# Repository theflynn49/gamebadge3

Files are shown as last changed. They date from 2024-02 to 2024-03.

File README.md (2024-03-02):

<b>New 2024 march 2</b> : Good news : all screens work, including the 7-pins ones ! 
Read the details in ST7789_280x240/TFT_adapt/README.md

This a a fork of BenHeck's GameBadge3 repo

I have a branch here "ST7789_280x240" where I made some changes
to support wider screens

There is also a TZT_adapt directory with gerber files for an adapter for cheap AliExpress screens (ST7789V screens with a connector layout like (Gnd/Vcc/Scl/Sda/Res/DC/CS/Blk)

To use it, modify code/Arduino libraries/pico_ST7789/pico_ST7789.cpp to set the width of your physical screen, i.e. 320, 280 or 240.
You should set also the appropriate rotation, leaving it to "1" if possible by rotating physically the screen (soldering it
in the left or right slot of the TZT adpter) 

If you do that, NOT-recompiled games may work on your screen without modifications,

exemple :
  #define SCR_WIDTH 320
  #define LCD_ROTATION 1

and then you should recompile.

Centering vertically has not been done yet, and will probably never be.

Don't forget to do all this on the correct branch :

<code>
git clone https://github.com/theflynn49/gamebadge3.git
git checkout ST7789_280x240
</code>

Warning : Games for GB3 must be compiled with 
  - flash size=1MB / Sketch Size=1MB
  - CPU Speed = 125Mhz (important !)
  - USB Stack : Adafruit TinyUSB



Have fun.
jF

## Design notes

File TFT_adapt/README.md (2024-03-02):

This is a kicad project for an adapter board to install a cheap Aliexpress TZT screen on your GameBadge.

Beware : BenHeck is NOT recommanding this, since cheap display modules may not work well.

On another hand, they cost about $3 instead of $17 as of today.

I tried these up to now :
 
 - <url>https://fr.aliexpress.com/item/1005005921876295.html</url> (round corners without pixels, upside-down)
 - <url>https://fr.aliexpress.com/item/1005005933513340.html</url> (tested OK, is upside-down)
 - <url>https://fr.aliexpress.com/item/32858069771.html</url> (7-wires, tested OK, is upside down)

For the 7-bit screen, you need to change gameBadgePico.cpp, and make the following change :
<code>
const struct st7789_config lcd_config = {
    .spi      = PICO_DEFAULT_SPI_INSTANCE,
    .gpio_din = PICO_DEFAULT_SPI_TX_PIN,
    .gpio_clk = PICO_DEFAULT_SPI_SCK_PIN,
    .gpio_cs  = PICO_DEFAULT_SPI_CSN_PIN,
    .gpio_dc  = 20,
    .gpio_rst = 21,
    .gpio_bl  = 22
};
</code>

has to be replaced by :
<code>
const struct st7789_config lcd_config = {
    .spi      = PICO_DEFAULT_SPI_INSTANCE,
    .gpio_din = PICO_DEFAULT_SPI_TX_PIN,
    .gpio_clk = PICO_DEFAULT_SPI_SCK_PIN,
    .gpio_cs  = -1, // <- to indicate only 7 pins, no CS
    .gpio_dc  = 20,
    .gpio_rst = 21,
    .gpio_bl  =  PICO_DEFAULT_SPI_CSN_PIN // <- if you use my TFT_adapt board this will be misrouted, so use CS instead of BLK
};
</code>
and you'll leave the pin "Blk" not connected on all connectors.
<br/>
Important note : make sure you use my version of gameBadgePico.cpp (as of 2024/02/24), which contains a modification to make the chinese TZT screen stable.
I pushed this mod on both my branches of this repo.

I tested the gerber files with PCBway.

This has been tested now, it works fine. 

Have fun.

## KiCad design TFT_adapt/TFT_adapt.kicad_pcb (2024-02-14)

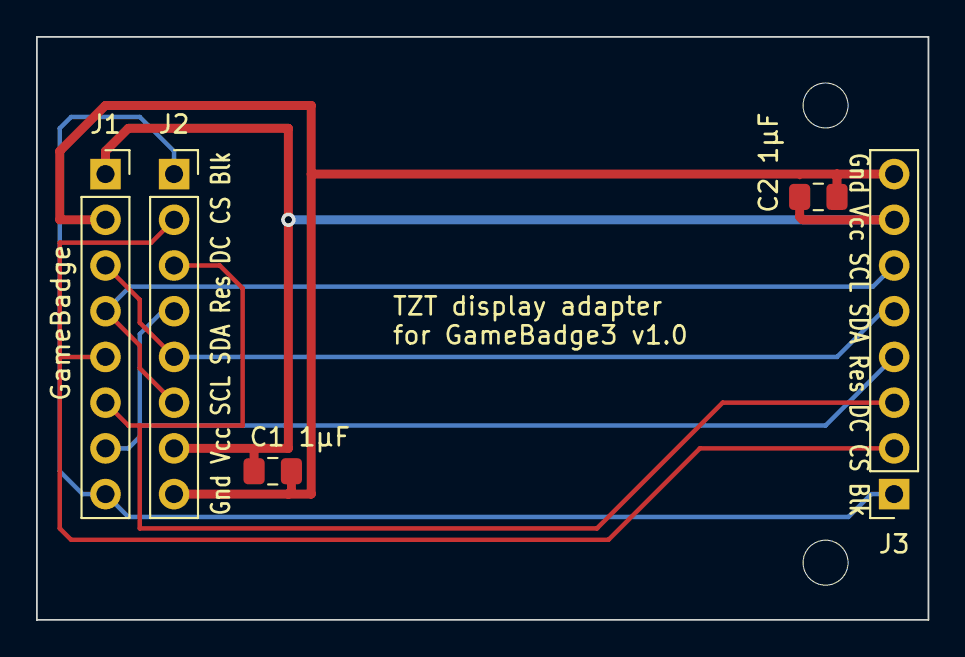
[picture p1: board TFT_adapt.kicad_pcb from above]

Board: 2 copper layers, 49.5 x 32.4 mm, 7 parts (0 on the bottom side), 8 nets.

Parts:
C1 1µF, C2 1µF: 1µF; C_0805_2012Metric_Pad1.18x1.45mm_HandSolder
H1, H2: MountingHole; MountingHole_2.5mm
J1, J2, J3: Conn_01x08; PinSocket_1x08_P2.54mm_Vertical

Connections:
unnamed: C1 1µF.1, C2 1µF.1, J1.1, J2.7, J3.7
unnamed: C1 1µF.2, C2 1µF.2, J1.2, J2.8, J3.8
unnamed: J1.3, J2.5, J3.5
unnamed: J1.4, J2.6, J3.6
unnamed: J1.5, J2.2, J3.2
unnamed: J1.6, J2.3, J3.3
unnamed: J1.7, J2.4, J3.4
unnamed: J1.8, J2.1, J3.1

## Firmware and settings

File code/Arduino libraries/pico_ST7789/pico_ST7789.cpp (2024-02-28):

//ST7789 driver for Pi Pico based Gamebadge3
//Uses this library mostly for setup then dumps data via DMA

#include "Arduino.h"
#include "pico_ST7789.h"

#include <string.h>
#include "hardware/gpio.h"

struct st7789_config st7789_cfg;
uint16_t st7789_width;
uint16_t st7789_height;
bool st7789_data_mode = false;

#define ST77XX_MADCTL_MY 0x80
#define ST77XX_MADCTL_MX 0x40

#define ST77XX_MADCTL_MV 0x20
#define ST77XX_MADCTL_ML 0x10

#define ST77XX_MADCTL_RGB 0x00

#define SCR_WIDTH 320    // Beware some 280x240 screens are in fact 320x240 screens

#define LCD_OFFSET_X ((SCR_WIDTH-240)/2) // set his to (screen width-240)/2, to set black bands left and right
#define SCR_OFFSET_X (320-SCR_WIDTH)     // set this to 320-screen width 
#define LCD_OFFSET_Y 0   // not used yet leave it to 0
#define LCD_ROTATION 1

uint8_t _xstart;
uint8_t _ystart;

void st7789_init(const struct st7789_config* config, uint16_t width, uint16_t height)
{
    memcpy(&st7789_cfg, config, sizeof(st7789_cfg));				//Copy referenced structure to our own copy
    st7789_width = width;
    st7789_height = height;

    spi_init(st7789_cfg.spi, 125 * 1000 * 1000);					//Set SPI to max speed, CPU must be 125Hz
    
    
    if (st7789_cfg.gpio_cs > -1) {
        spi_set_format(st7789_cfg.spi, 8, SPI_CPOL_0, SPI_CPHA_0, SPI_MSB_FIRST);
    } else {
        spi_set_format(st7789_cfg.spi, 8, SPI_CPOL_1, SPI_CPHA_1, SPI_MSB_FIRST);
    }

    gpio_set_function(st7789_cfg.gpio_din, GPIO_FUNC_SPI);
    gpio_set_function(st7789_cfg.gpio_clk, GPIO_FUNC_SPI);

    if (st7789_cfg.gpio_cs > -1) {
        gpio_init(st7789_cfg.gpio_cs);
    }
    gpio_init(st7789_cfg.gpio_dc);
    gpio_init(st7789_cfg.gpio_rst);
    gpio_init(st7789_cfg.gpio_bl);

    if (st7789_cfg.gpio_cs > -1) {
        gpio_set_dir(st7789_cfg.gpio_cs, GPIO_OUT);
    }
    gpio_set_dir(st7789_cfg.gpio_dc, GPIO_OUT);
    gpio_set_dir(st7789_cfg.gpio_rst, GPIO_OUT);
    gpio_set_dir(st7789_cfg.gpio_bl, GPIO_OUT);

	gpio_put(st7789_cfg.gpio_bl, 1);

    if (st7789_cfg.gpio_cs > -1) {
        gpio_put(st7789_cfg.gpio_cs, 1);
    }
    gpio_put(st7789_cfg.gpio_dc, 1);
	gpio_put(st7789_cfg.gpio_rst, 0);
	sleep_ms(150);
    gpio_put(st7789_cfg.gpio_rst, 1);
    sleep_ms(100);
    
    // SWRESET (01h): Software Reset
    st7789_cmd(0x01, NULL, 0);
    sleep_ms(150);

    // SLPOUT (11h): Sleep Out
    st7789_cmd(0x11, NULL, 0);
    sleep_ms(10);

	st7789_setRotation(LCD_ROTATION);

    // COLMOD (3Ah): Interface Pixel Format
    // - RGB interface color format     = 65K of RGB interface
    // - Control interface color format = 16bit/pixel

    //uint8_t cmd = 0x2c;
    //spi_write_blocking(st7789_cfg.spi, &cmd, sizeof(cmd));
    
    uint8_t cmd = 0x55;
    st7789_cmd(0x3a, &cmd, 1);
    sleep_ms(10);

    st7789_caset(0, width - 1);
    st7789_raset(0, height - 1);
	
    // INVON (21h): Display Inversion On
    st7789_cmd(0x21, NULL, 0);
    sleep_ms(10);

    // NORON (13h): Normal Display Mode On
    st7789_cmd(0x13, NULL, 0);
    sleep_ms(10);

    st7789_razmem() ;
    
    // DISPON (29h): Display On
    st7789_cmd(0x29, NULL, 0);
    sleep_ms(10);
	 
}

void st7789_backlight(bool state) {

	if (state == true) {
		gpio_put(st7789_cfg.gpio_bl, 1);
	}
	else {
		gpio_put(st7789_cfg.gpio_bl, 0);
	}
	
}

void st7789_cmd(uint8_t cmd, const uint8_t* data, size_t len)
{
    if (st7789_cfg.gpio_cs > -1) {
        spi_set_format(st7789_cfg.spi, 8, SPI_CPOL_0, SPI_CPHA_0, SPI_MSB_FIRST);
    } else {
        spi_set_format(st7789_cfg.spi, 8, SPI_CPOL_1, SPI_CPHA_1, SPI_MSB_FIRST);
    }
    st7789_data_mode = false;

    sleep_us(1);
    if (st7789_cfg.gpio_cs > -1) {
        gpio_put(st7789_cfg.gpio_cs, 0);
    }
    gpio_put(st7789_cfg.gpio_dc, 0);
    sleep_us(1);
    
    spi_write_blocking(st7789_cfg.spi, &cmd, sizeof(cmd));
    
    if (len) {
        sleep_us(1);
        gpio_put(st7789_cfg.gpio_dc, 1);
        sleep_us(1);
        
        spi_write_blocking(st7789_cfg.spi, data, len);
    }

    sleep_us(1);
    if (st7789_cfg.gpio_cs > -1) {
        gpio_put(st7789_cfg.gpio_cs, 1);
    }
    gpio_put(st7789_cfg.gpio_dc, 1);
    sleep_us(1);
}


void st7789_rascaset(uint8_t cmd, uint16_t xs, uint16_t xe, uint16_t offset)
{
	uint8_t data[4];
        uint16_t _tmp ;
	
        _tmp = xs+offset ;
	data[0] = _tmp >> 8;
	data[1] = _tmp & 0xFF;
        _tmp = xe+offset ;
	data[2] = _tmp >> 8;
	data[3] = _tmp & 0xFF;
	
        st7789_cmd(cmd, data, sizeof(data));			// CASET (2Ah): Column Address Set
}

inline void st7789_caset(uint16_t xs, uint16_t xe)
{
        st7789_rascaset(0x2a, xs, xe, LCD_OFFSET_X) ;
}

inline void st7789_raset(uint16_t ys, uint16_t ye)
{
        st7789_rascaset(0x2b, ys, ye, LCD_OFFSET_Y) ;
}

void st7789_ramwr()
{
    sleep_us(1);
    if (st7789_cfg.gpio_cs > -1) {
        gpio_put(st7789_cfg.gpio_cs, 0);
    }
    gpio_put(st7789_cfg.gpio_dc, 0);
    sleep_us(1);

    // RAMWR (2Ch): Memory Write
    uint8_t cmd = 0x2c;
    spi_write_blocking(st7789_cfg.spi, &cmd, sizeof(cmd));

    sleep_us(1);

	if (st7789_cfg.gpio_cs > -1) {
		gpio_put(st7789_cfg.gpio_cs, 0);
		spi_set_format(st7789_cfg.spi, 16, SPI_CPOL_0, SPI_CPHA_0, SPI_MSB_FIRST);
	} else {
		spi_set_format(st7789_cfg.spi, 16, SPI_CPOL_1, SPI_CPHA_1, SPI_MSB_FIRST);
	}	

    gpio_put(st7789_cfg.gpio_dc, 1);
    sleep_us(1);
}

void st7789_set_cursor(uint16_t x, uint16_t y)
{
    st7789_caset(x, st7789_width - 1);
    st7789_raset(y, st7789_height - 1);
}

void st7789_setRotation(uint8_t which) {
	
  uint8_t cmd = 0;

  switch (which & 0x03) {
	  case 0:
		cmd = ST77XX_MADCTL_MX | ST77XX_MADCTL_MY | ST77XX_MADCTL_RGB;
		_xstart = 0;
		_ystart = 80;
		break;
	  case 1:
		cmd = ST77XX_MADCTL_MY | ST77XX_MADCTL_MV | ST77XX_MADCTL_RGB;
		_xstart = SCR_OFFSET_X;  
		_ystart = 0;
		break;
	  case 2:
		cmd = ST77XX_MADCTL_RGB;
		_xstart = 0;
		_ystart = 0;
		break;
	  case 3:
		cmd = ST77XX_MADCTL_MX | ST77XX_MADCTL_MV | ST77XX_MADCTL_RGB;
		_xstart = 0;
		_ystart = 0;
		break;
  }

  st7789_cmd(0x36, &cmd, 1);
	
}

void st7789_setAddressWindow(uint16_t x, uint16_t y, uint16_t w, uint16_t h) {
	
	x += _xstart;
	y += _ystart;
	uint32_t xa = ((uint32_t)x << 16) | (x + w - 1);
	uint32_t ya = ((uint32_t)y << 16) | (y + h - 1);

	st7789_caset(x, x + (w - 1));		 // Column addr set
	st7789_raset(y, y + (h - 1)); 		// Row addr set

}
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

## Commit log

2024-02-14 Add kicad files for a screen adapter board to fit cheap asian screens
    [TFT_adapt.kicad_pcb, TFT_adapt.kicad_sch]
2024-02-24 Improve screen stability by insuring there is a 1µs delay after a dma transfer is done before starting a new one. This modification insure that there is no collision with a previous block, so the pre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
    A few other modifications have been made removing some constants and uselesss calls.
2024-02-25 Before starting a new DMA cycle, we need to wait that the previous DMA is finished AND that the SPI is empty !
2024-02-28 The screen shift was not working for Rotation==1; this is fixed now, and I cleaned up that code a bit.
    [pico_ST7789.cpp]
